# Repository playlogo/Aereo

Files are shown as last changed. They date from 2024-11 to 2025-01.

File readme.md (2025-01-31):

# Aereo - CO2 & PM2.5 Air Sensor with custom PCB

A DIY IoT air-quality sensor using a `Senseair S8` for CO2 and a `PMS5003` for particulate matter.

Features:

- ESP32c3 firmware to publish measurements to influxDB
- Custom PCB for easy assembly
- Grafana dashboard to display data

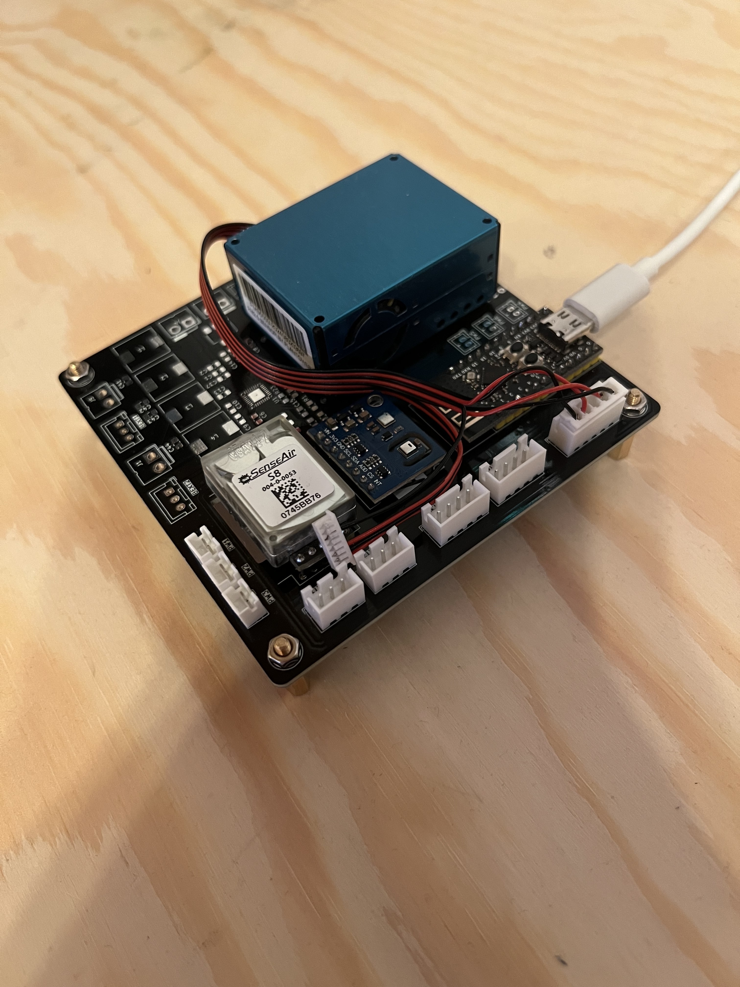
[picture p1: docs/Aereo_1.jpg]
Picture of assembeld Aereo PCB
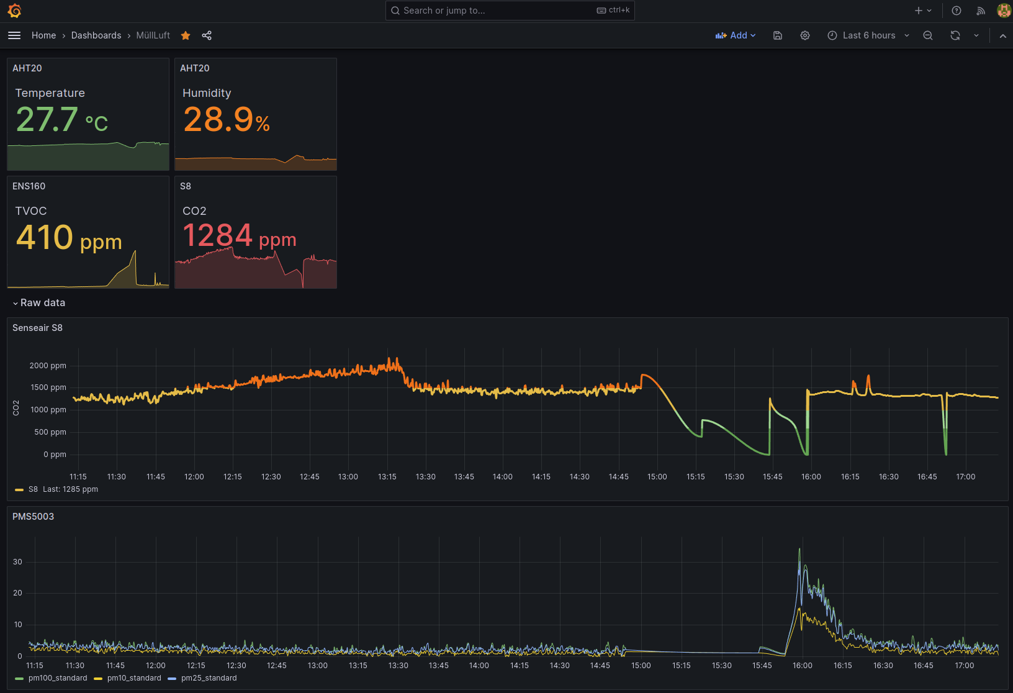
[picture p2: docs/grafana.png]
Screenshot of the grafana dashboard
|||
|-|-|
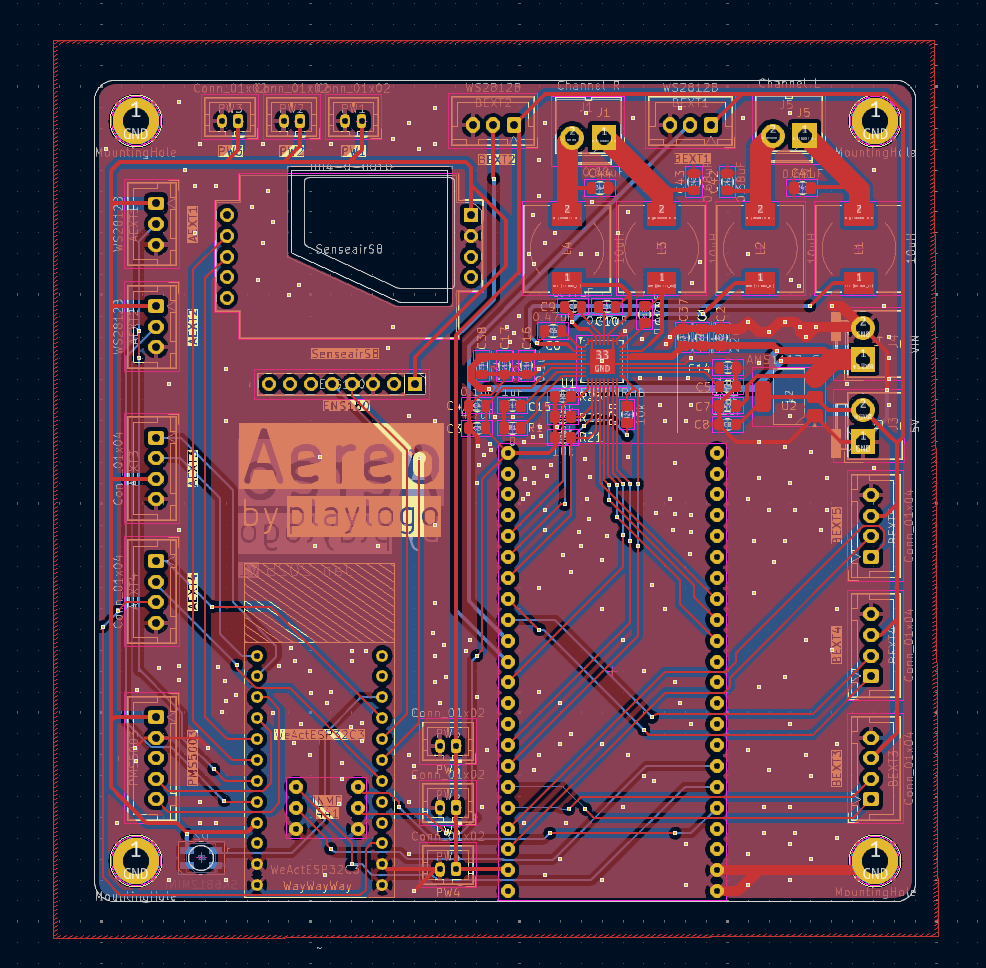
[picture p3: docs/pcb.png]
Picture of PCB design in KiCAD
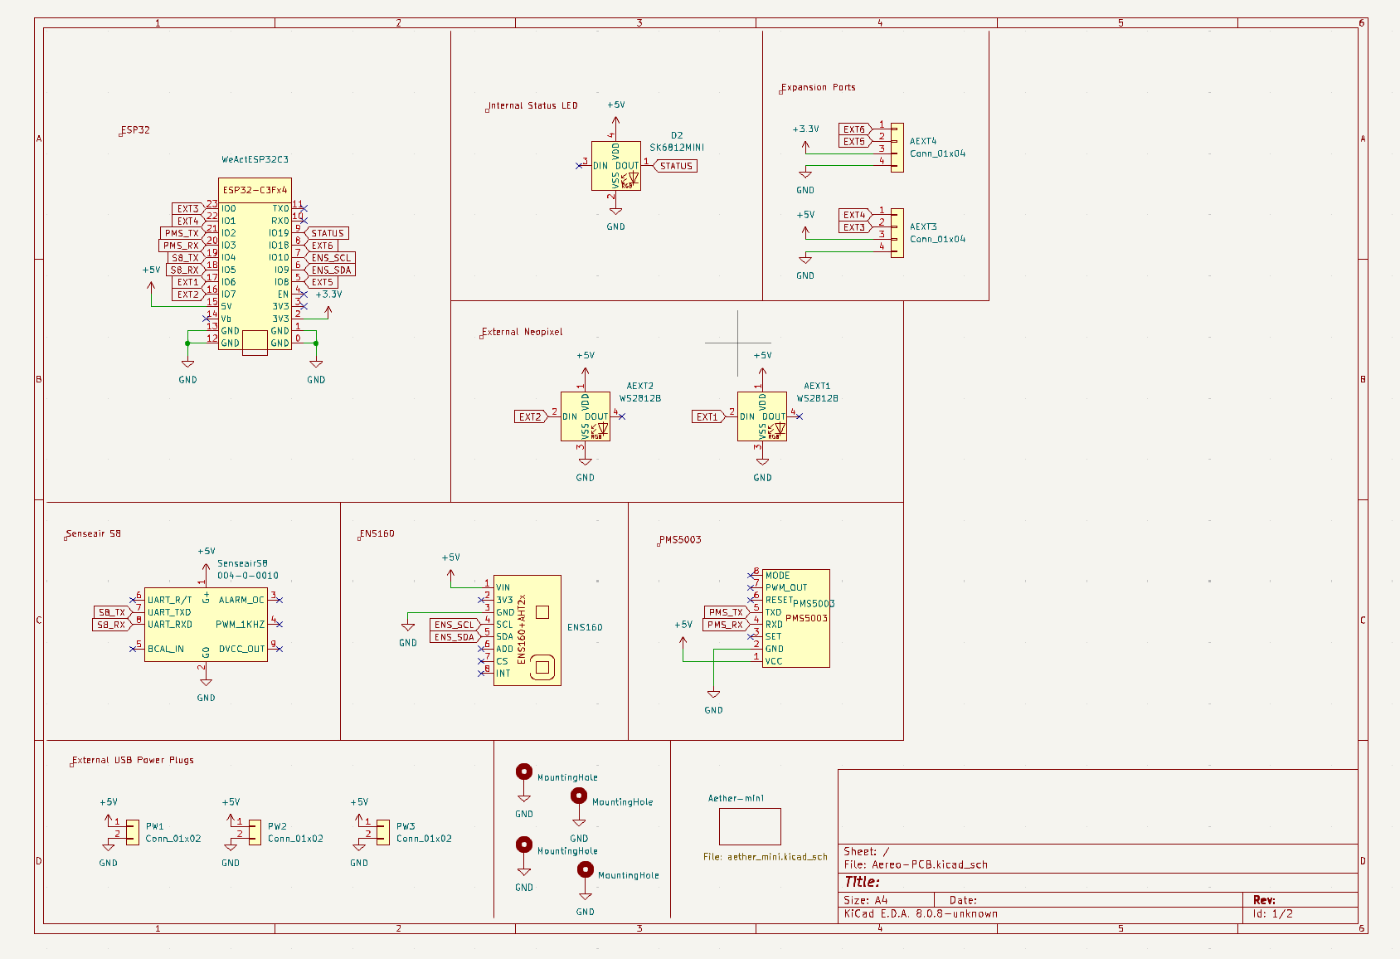
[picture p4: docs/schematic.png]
|||

## Tutorial

### Installing InfluxDB & Grafana using docker

1. Clone this repo: `git clone https://github.com/playlogo/Aereo.git`
2. Run `docker compose up -d`

3. Setup Grafana at: `http://<ip>:3000`
4. Setup InfluxDB at: `http://<ip>:8086`

5. Follow [this guide](https://www.influxdata.com/blog/getting-started-influxdb-grafana/) to add InfluxDB as a Datasource to Grafana
6. Import the Grafana dashboard:
    - Create a new empty dashboard: `Home` -> `Dashboards` -> `New`
    - Click the little gear icon to get to the `Dashboard Settings`
    - Go to the `JSON Model` tab
    - Copy the contents of the `grafana_dashboard.json` file and paste them into the editor
    - Hit `Save Changes` and reload - voilà (you might still need to change the Datasource of each Graph to the one you just created)

Optional: Create your own dashboard following the guide linked above (don't forget to hit save!)

### Flashing the ESP32c3

1. Open `.vscode/Aereo.code-workspace` using VSCode, make sure you have [PlatformIO](https://platformio.org/install/ide?install=vscode) installed and setup
2. Create `Aereo/src/secrets.h` with the following content:

```cpp
#define WIFI_SSID "NEIGHBORS_WIFI"
#define WIFI_PASSWORD "123456789"

#define INFLUXDB_URL "http://192.168.178.64:8086/"
#define INFLUXDB_TOKEN "token please" // Guide: https://docs.influxdata.com/influxdb3/cloud-serverless/admin/tokens/create-token/
#define INFLUXDB_ORG "bumble"
#define INFLUXDB_BUCKET "aereo" // Guide: https://docs.influxdata.com/influxdb/v2/admin/buckets/create-bucket/
```

3. Build & Upload to the ESP32c3: `CTRL+P` -> `PlatformIO: Upload`
4. The neopixel should blink blue while the ESP connects to wifi, when connected it should turn off - if it continues showing one static color, one of the sensors has not been detected -> Check serial output: `CTRL+P` -> `PlatformIO: Upload and Monitor`

## Hardware

Required components:

- `ENS160-AHT21`: Temp + TVOC sensor ~4€ on aliexpress
- `Senseair S8`: [NDIR](https://en.wikipedia.org/wiki/Nondispersive_infrared_sensor) CO2 Sensor ~20€ on aliexpress
- `PMS5003`:  Particulate matter sensor ~14€ on aliexpress
- `WeAct ESP32C3 CoreBoard`: ~4€ on aliexpress
- `SK6812 mini e`: 1x ARGB status LED ~3€ on aliexpress (for 100pcs)

PCB:

- Houses two independent projects to save costs, the right half can simply be ignored
- Exposed connectors:
  - 2x 3 Pin (5V, GND, Data)
  - 2x 4 Pin (5V, GND, Data, Data)
  - 3x Power (5V, GND)
- Size: 100x100mm

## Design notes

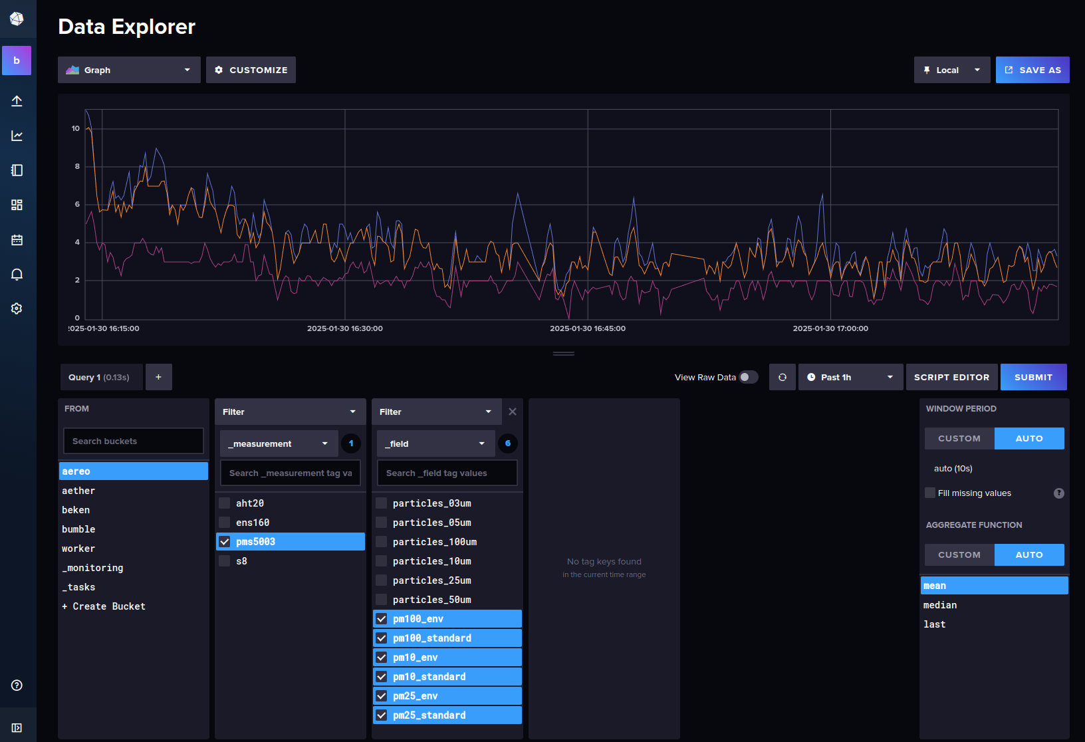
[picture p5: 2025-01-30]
docs/influxDB.png

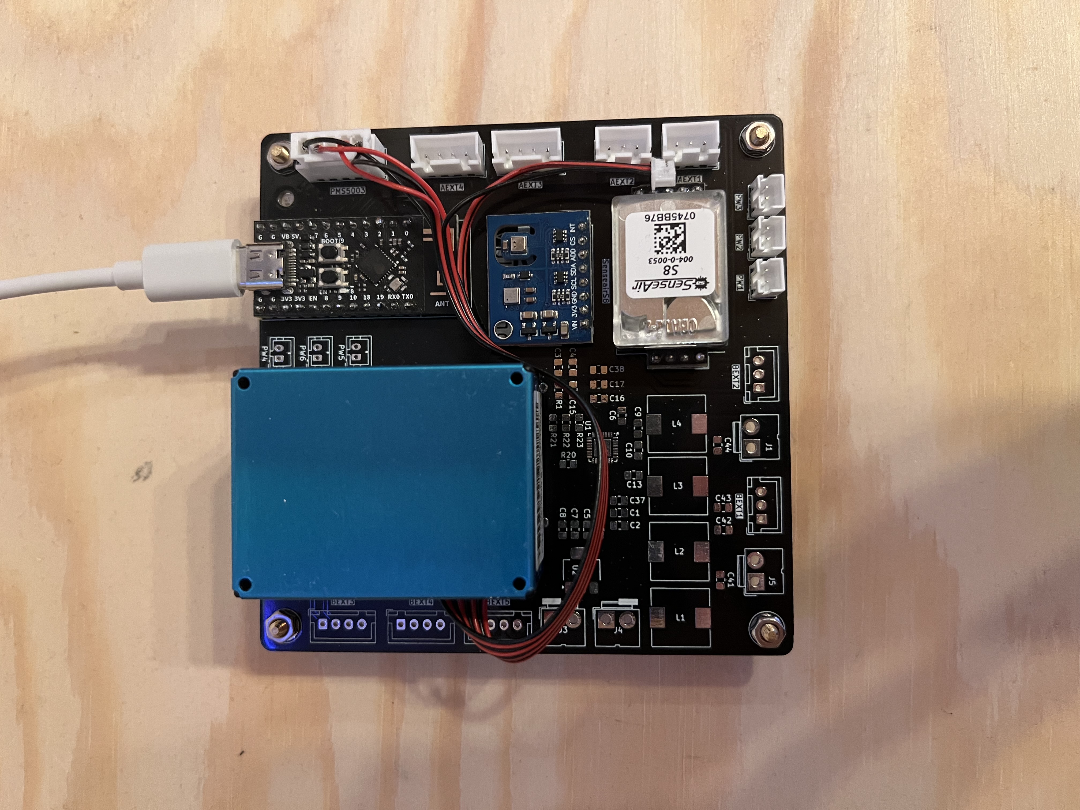
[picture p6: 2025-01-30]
docs/Aereo_2.jpg

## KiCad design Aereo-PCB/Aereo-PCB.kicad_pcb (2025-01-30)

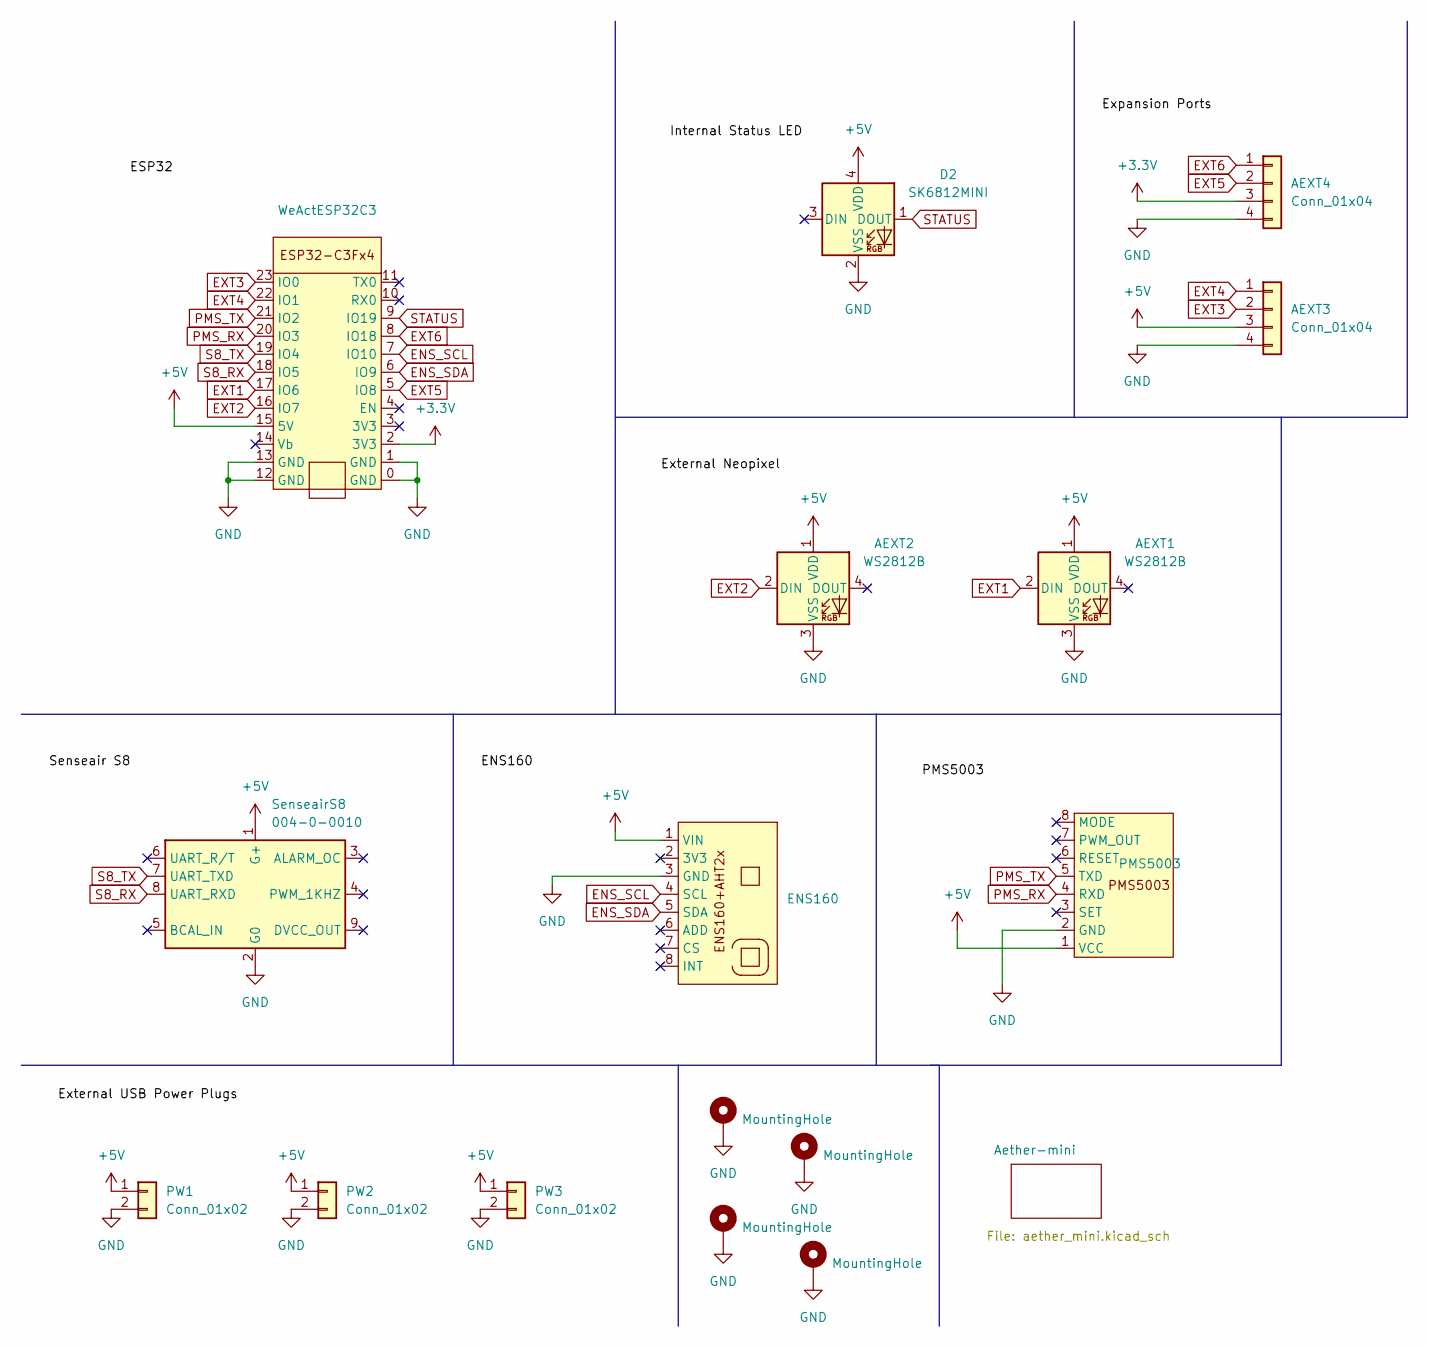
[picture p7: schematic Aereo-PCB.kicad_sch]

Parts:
AEXT1, AEXT2: WS2812B; JST_XH_B3B-XH-A_1x03_P2.50mm_Vertical
AEXT3, AEXT4: Conn_01x04; JST_XH_B4B-XH-A_1x04_P2.50mm_Vertical
D2: SK6812MINI; LED_SK6812MINI_PLCC4_3.5x3.5mm_P1.75mm
ENS160: PinHeader_1x08_P2.54mm_Vertical
H1, H2, H3, H4: MountingHole; MountingHole_3.2mm_M3_DIN965_Pad
PMS5003: JST_XH_B5B-XH-A_1x05_P2.50mm_Vertical
PW1, PW2, PW3: Conn_01x02; JST_PH_B2B-PH-K_1x02_P2.00mm_Vertical
SenseairS8: 004-0-0010; Senseair_S8_Down
WeActESP32C3: WeAct ESP32-C3Fx4 Core mini

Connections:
+3.3V: AEXT4.3, WeActESP32C3.2 (3V3)
+5V: AEXT1.1 (VDD), AEXT2.1 (VDD), AEXT3.3, D2.4 (VDD), ENS160.1 (VIN), PMS5003.1 (VCC), PW1.1, PW2.1, PW3.1, SenseairS8.1 (G+), WeActESP32C3.15 (5V)
ENS_SCL: ENS160.4 (SCL), WeActESP32C3.7 (IO10)
ENS_SDA: ENS160.5 (SDA), WeActESP32C3.6 (IO9)
EXT1: AEXT1.2 (DIN), WeActESP32C3.17 (IO6)
EXT2: AEXT2.2 (DIN), WeActESP32C3.16 (IO7)
EXT3: AEXT3.2, WeActESP32C3.23 (IO0)
EXT4: AEXT3.1, WeActESP32C3.22 (IO1)
EXT5: AEXT4.2, WeActESP32C3.5 (IO8)
EXT6: AEXT4.1, WeActESP32C3.8 (IO18)
GND: AEXT1.3 (VSS), AEXT2.3 (VSS), AEXT3.4, AEXT4.4, D2.2 (VSS), ENS160.3 (GND), H1.1, H2.1, H3.1, H4.1, PMS5003.2 (GND), PW1.2, PW2.2, PW3.2, SenseairS8.2 (G0), WeActESP32C3.0 (GND), WeActESP32C3.1 (GND), WeActESP32C3.12 (GND), WeActESP32C3.13 (GND); also elsewhere on the board
PMS_RX: PMS5003.4 (RXD), WeActESP32C3.20 (IO3)
PMS_TX: PMS5003.5 (TXD), WeActESP32C3.21 (IO2)
S8_RX: SenseairS8.8 (UART_RXD), WeActESP32C3.18 (IO5)
S8_TX: SenseairS8.7 (UART_TXD), WeActESP32C3.19 (IO4)
STATUS: D2.1 (DOUT), WeActESP32C3.9 (IO19)

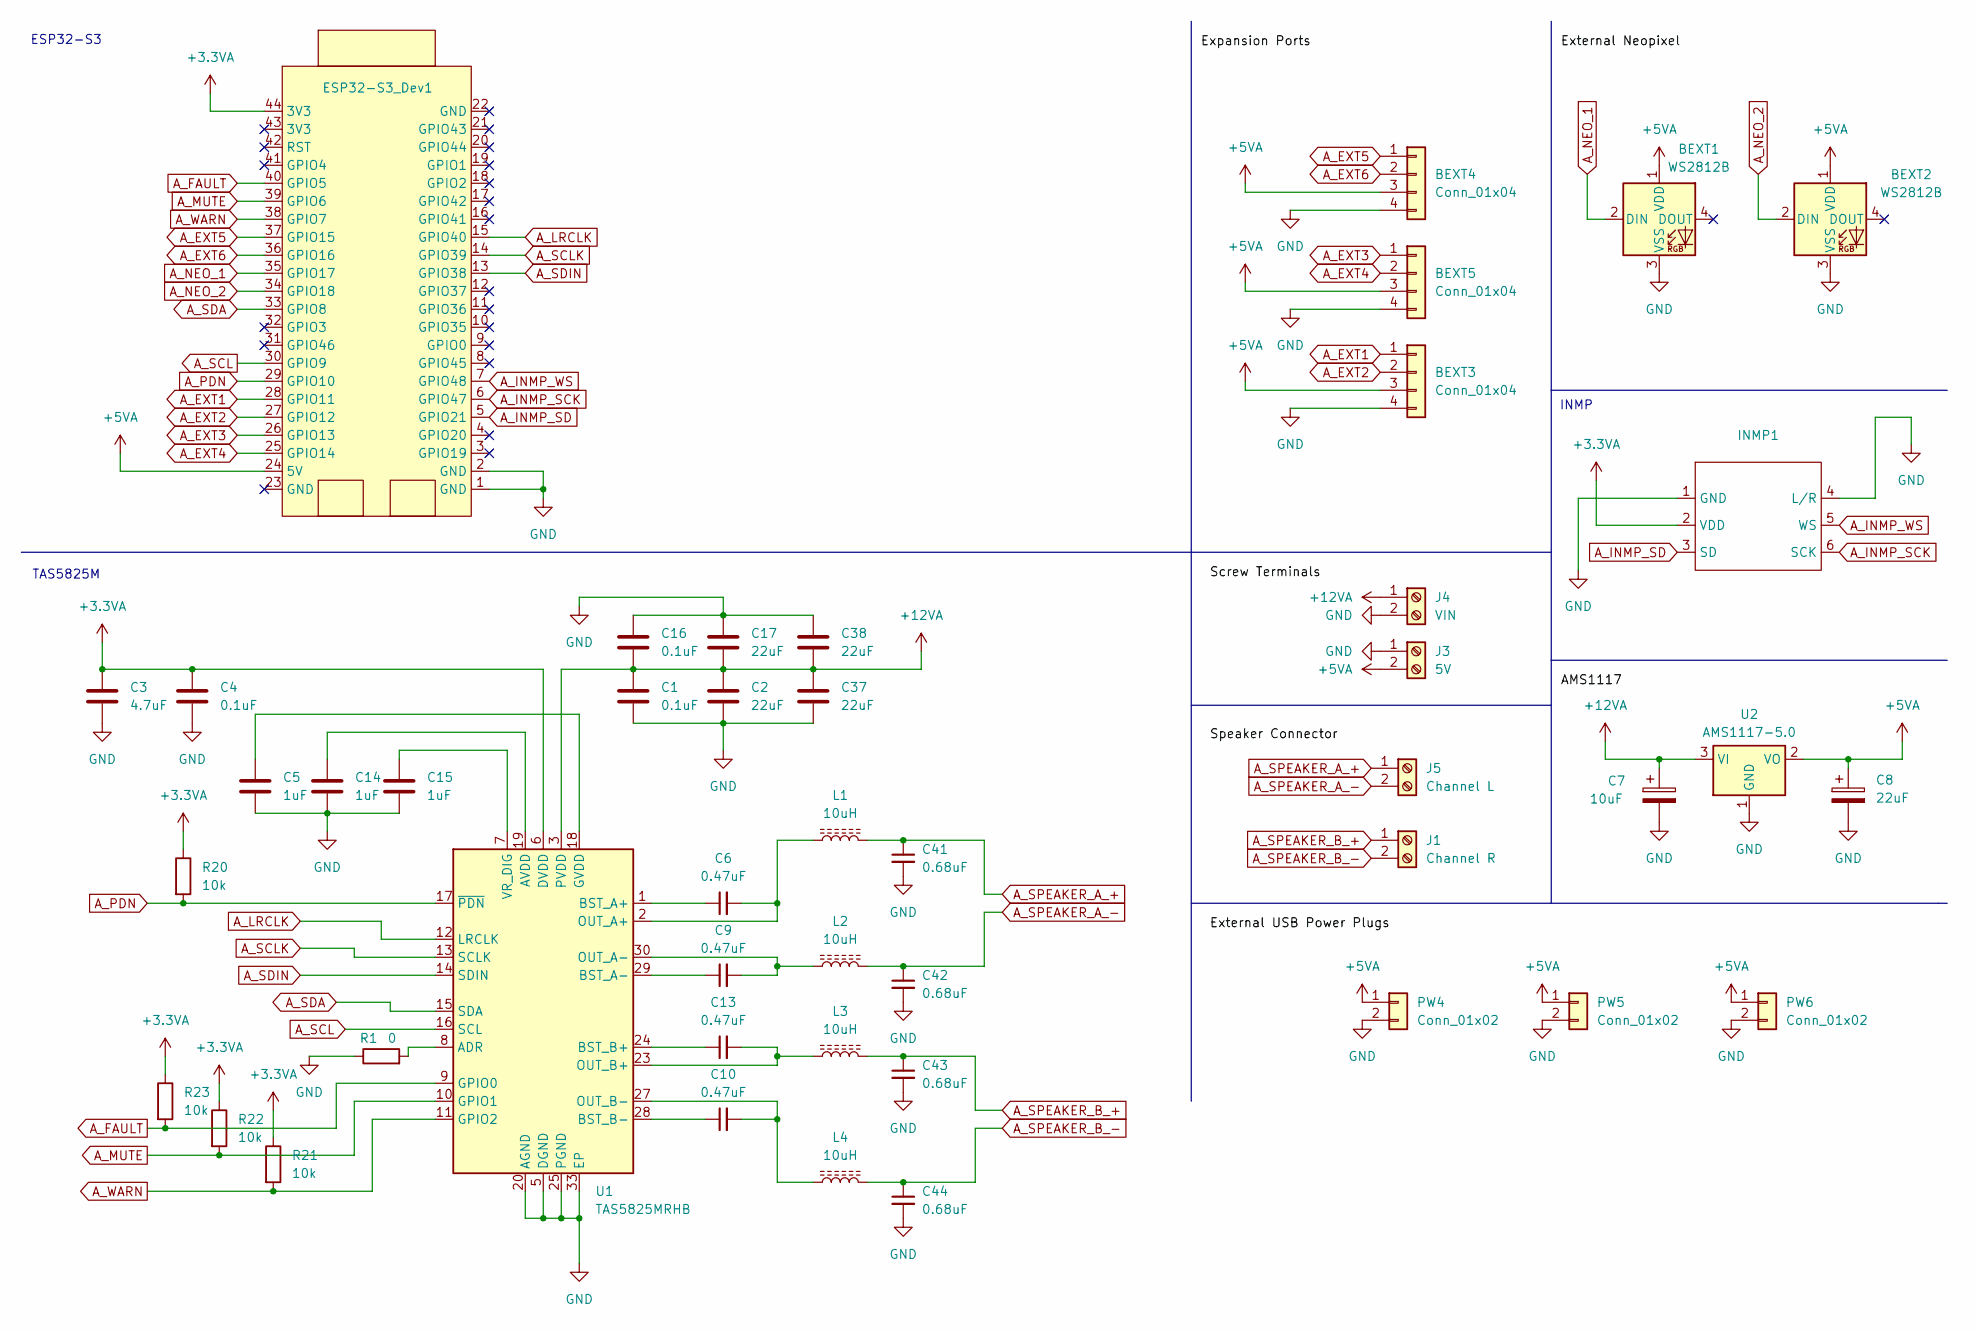
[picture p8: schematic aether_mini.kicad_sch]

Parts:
BEXT1, BEXT2: WS2812B; JST_XH_B3B-XH-A_1x03_P2.50mm_Vertical
BEXT3, BEXT4, BEXT5: Conn_01x04; JST_XH_B4B-XH-A_1x04_P2.50mm_Vertical
C1, C4, C16: 0.1uF; C_0805_2012Metric_Pad1.18x1.45mm_HandSolder
C2, C8, C17, C37, C38: 22uF; C_0805_2012Metric_Pad1.18x1.45mm_HandSolder
C3: 4.7uF; C_0805_2012Metric_Pad1.18x1.45mm_HandSolder
C5, C14, C15: 1uF; C_0805_2012Metric_Pad1.18x1.45mm_HandSolder
C6, C9, C10, C13: 0.47uF; C_0805_2012Metric_Pad1.18x1.45mm_HandSolder
C7: 10uF; C_0805_2012Metric_Pad1.18x1.45mm_HandSolder
C41, C42, C43, C44: 0.68uF; C_0805_2012Metric_Pad1.18x1.45mm_HandSolder
ESP32-S3_Dev1: ESP32-S3-Dev
INMP1: INMP441
J1: Channel R; JWT_A3963_1x02_P3.96mm_Vertical
J3: 5V; JWT_A3963_1x02_P3.96mm_Vertical
J4: VIN; JWT_A3963_1x02_P3.96mm_Vertical
J5: Channel L; JWT_A3963_1x02_P3.96mm_Vertical
L1, L2, L3, L4: 10uH; L_10.4x10.4_H4.8
PW4, PW5, PW6: Conn_01x02; JST_PH_B2B-PH-K_1x02_P2.00mm_Vertical
R1: 0; R_0805_2012Metric_Pad1.20x1.40mm_HandSolder
R20, R21, R22, R23: 10k; R_0805_2012Metric_Pad1.20x1.40mm_HandSolder
U1: TAS5825MRHB; VQFN-32-1EP_5x5mm_P0.5mm_EP3.1x3.1mm
U2: AMS1117-5.0; SOT-223-3_TabPin2

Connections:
+3.3VA: C3.1, C4.1, ESP32-S3_Dev1.44 (3V3), INMP1.2 (VDD), R20.1, R21.1, R22.1, R23.1, U1.6 (DVDD)
+5VA: BEXT1.1 (VDD), BEXT2.1 (VDD), BEXT3.3, BEXT4.3, BEXT5.3, C8.1, ESP32-S3_Dev1.24 (5V), J3.2, PW4.1, PW5.1, PW6.1, U2.2 (VO)
+12VA: C1.1, C2.1, C7.1, C16.2, C17.2, C37.1, C38.2, J4.1, U1.3 (PVDD), U1.4 (PVDD), U1.21 (PVDD), U1.22 (PVDD), U2.3 (VI)
A_EXT1: BEXT3.1, ESP32-S3_Dev1.28 (GPIO11)
A_EXT2: BEXT3.2, ESP32-S3_Dev1.27 (GPIO12)
A_EXT3: BEXT5.1, ESP32-S3_Dev1.26 (GPIO13)
A_EXT4: BEXT5.2, ESP32-S3_Dev1.25 (GPIO14)
A_EXT5: BEXT4.1, ESP32-S3_Dev1.37 (GPIO15)
A_EXT6: BEXT4.2, ESP32-S3_Dev1.36 (GPIO16)
A_FAULT: ESP32-S3_Dev1.40 (GPIO5), R23.2, U1.9 (GPIO0)
A_INMP_SCK: ESP32-S3_Dev1.6 (GPIO47), INMP1.6 (SCK)
A_INMP_SD: ESP32-S3_Dev1.5 (GPIO21), INMP1.3 (SD)
A_INMP_WS: ESP32-S3_Dev1.7 (GPIO48), INMP1.5 (WS)
A_LRCLK: ESP32-S3_Dev1.15 (GPIO40), U1.12 (LRCLK)
A_MUTE: ESP32-S3_Dev1.39 (GPIO6), R22.2, U1.10 (GPIO1)
A_NEO_1: BEXT1.2 (DIN), ESP32-S3_Dev1.35 (GPIO17)
A_NEO_2: BEXT2.2 (DIN), ESP32-S3_Dev1.34 (GPIO18)
A_PDN: ESP32-S3_Dev1.29 (GPIO10), R20.2, U1.17 (~PDN)
A_SCL: ESP32-S3_Dev1.30 (GPIO9), U1.16 (SCL)
A_SCLK: ESP32-S3_Dev1.14 (GPIO39), U1.13 (SCLK)
A_SDA: ESP32-S3_Dev1.33 (GPIO8), U1.15 (SDA)
A_SDIN: ESP32-S3_Dev1.13 (GPIO38), U1.14 (SDIN)
A_SPEAKER_A_+: C41.1, J5.1, L1.2
A_SPEAKER_A_-: C42.1, J5.2, L2.2
A_SPEAKER_B_+: C43.1, J1.1, L3.2
A_SPEAKER_B_-: C44.1, J1.2, L4.2
A_WARN: ESP32-S3_Dev1.38 (GPIO7), R21.2, U1.11 (GPIO2)
GND: BEXT1.3 (VSS), BEXT2.3 (VSS), BEXT3.4, BEXT4.4, BEXT5.4, C1.2, C2.2, C3.2, C4.2, C5.2, C7.2, C8.2, C14.2, C15.2, C16.1, C17.1, C37.2, C38.1, C41.2, C42.2, C43.2, C44.2, ESP32-S3_Dev1.1 (GND), ESP32-S3_Dev1.2 (GND), INMP1.1 (GND), INMP1.4 (L/R), J3.1, J4.2, PW4.2, PW5.2, PW6.2, R1.1, U1.5 (DGND), U1.20 (AGND), U1.25 (PGND), U1.26 (PGND), U1.31 (PGND), U1.32 (PGND), U1.33 (EP), U2.1 (GND); also elsewhere on the board
unnamed: R1.2, U1.8 (ADR)
unnamed: C14.1, U1.19 (AVDD)
unnamed: C6.1, U1.1 (BST_A+)
unnamed: C9.1, U1.29 (BST_A-)
unnamed: C13.1, U1.24 (BST_B+)
unnamed: C10.1, U1.28 (BST_B-)
unnamed: C5.1, U1.18 (GVDD)
unnamed: C6.2, L1.1, U1.2 (OUT_A+)
unnamed: C9.2, L2.1, U1.30 (OUT_A-)
unnamed: C13.2, L3.1, U1.23 (OUT_B+)
unnamed: C10.2, L4.1, U1.27 (OUT_B-)
unnamed: C15.1, U1.7 (VR_DIG)

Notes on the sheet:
ESP32-S3
INMP
TAS5825M

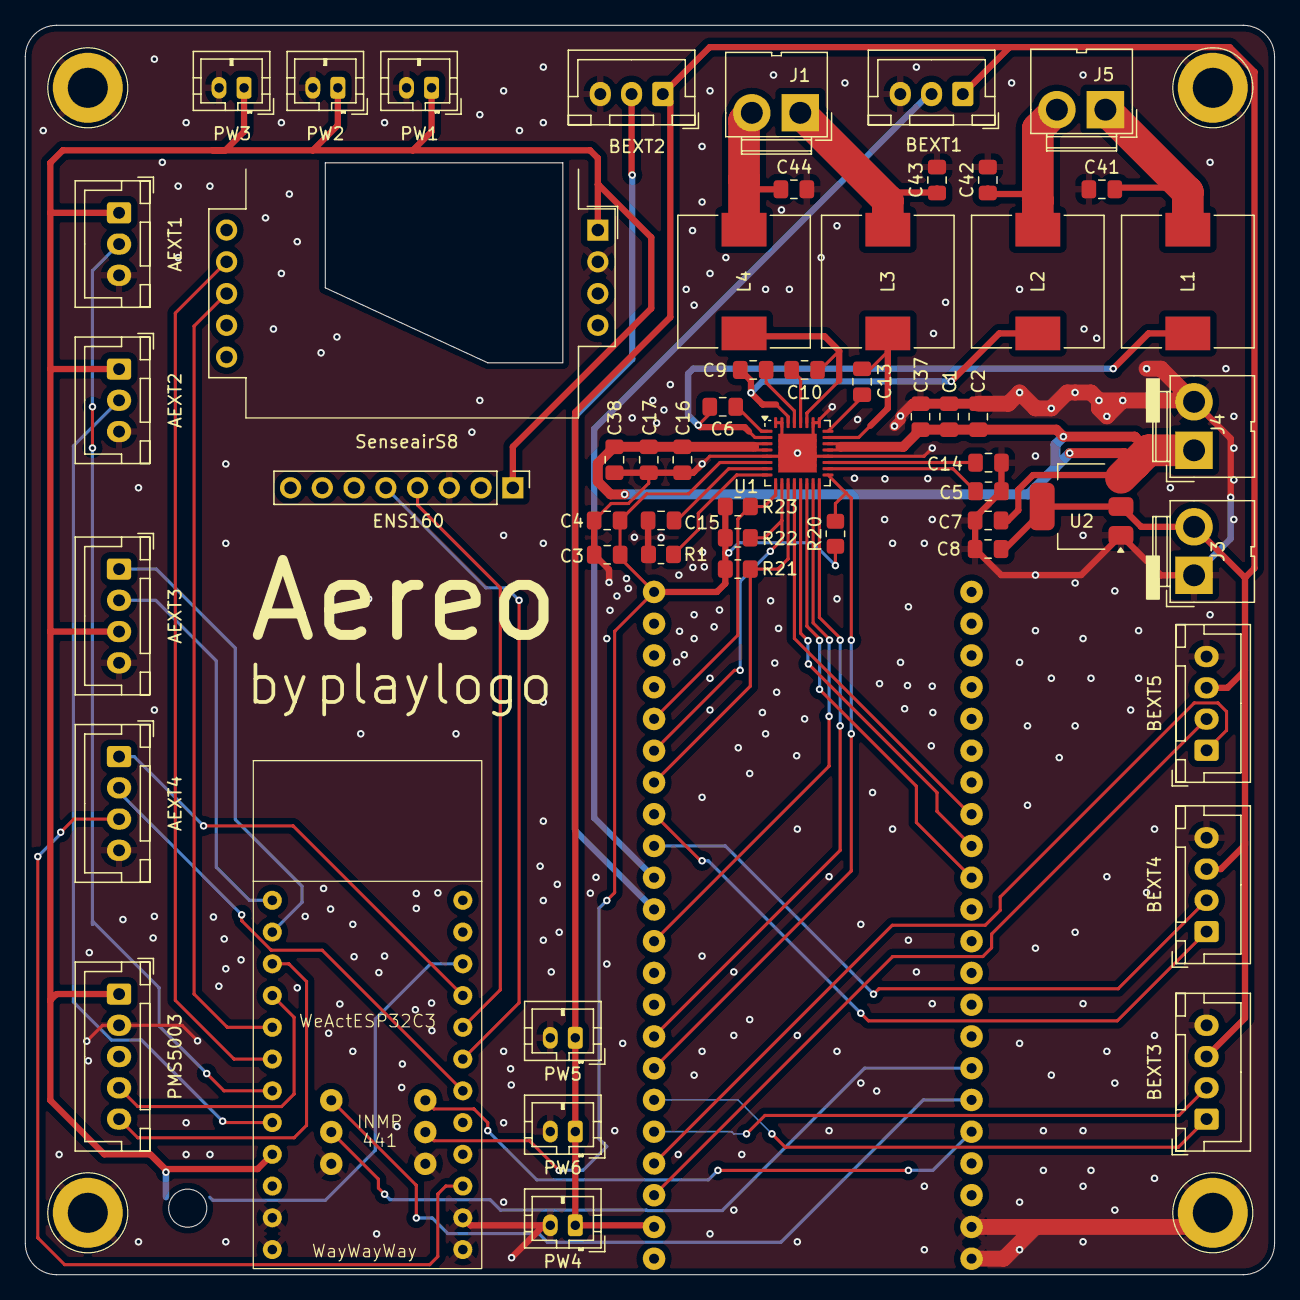
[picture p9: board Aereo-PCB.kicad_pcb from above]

Board: 2 copper layers, 99.9 x 99.9 mm, 62 parts (1 on the bottom side), 55 nets.

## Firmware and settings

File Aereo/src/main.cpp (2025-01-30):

#include <Arduino.h>

// Sensors
#include "sensors/pms5003.h"
#include "sensors/aht20.h"
#include "sensors/s8.h"

// Utils
#include "utils/influxdb.h"

// Neopixel
#include "utils/neopixel.h"

// Setup
void setup()
{
    Serial.begin(115200);

    neopixelSetup();

    wifiConnect();
    influxDBSetup();

    // Sensors
    bool enable_PMS5003 = setupPMS5003();
    bool enable_AHT20AndENS160 = setupAHT20AndENS160();
    bool enable_S8 = setupS8();

    // FreeRTOS
    if (enable_PMS5003)
    {
        xTaskCreate(loopPMS5003, "loopPMS5003", 10000, NULL, 1, NULL);
    }

    if (enable_AHT20AndENS160)
    {
        xTaskCreate(loopAHT20, "loopAHT20", 10000, NULL, 1, NULL);
        xTaskCreate(loopENS160, "loopENS160", 10000, NULL, 1, NULL);
    }

    if (enable_S8)
    {
        xTaskCreate(loopS8, "loopS8", 10000, NULL, 1, NULL);
    }

    setColor(enable_PMS5003 ? 0 : 40, enable_AHT20AndENS160 ? 0 : 40, enable_S8 ? 0 : 40);
}

void loop()
{
    delay(1000);
}

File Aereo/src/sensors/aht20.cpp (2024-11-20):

#include "aht20.h"

#include "../utils/common.h"
#include "../utils/influxdb.h"

#include <Wire.h>
#include <Adafruit_AHTX0.h>
#include <ScioSense_ENS160.h>

ScioSense_ENS160 ens160(ENS160_I2CADDR_1);
Adafruit_AHTX0 aht;

int tempC;
int humidity;

Point Sensor_AHT20("aht20");
Point Sensor_ENS160("ens160");

bool setupAHT20AndENS160()
{
    // AHT20Swtich
    Wire.setPins(9, 10); // Switch I2C pins

    if (!aht.begin())
    {
        Serial.println("AHT20 sensor not found!");
        return false;
    }
    else
    {
        Serial.println("AHT20 sensor found!");
    }

    // ENS160
    ens160.begin();

    if (ens160.available())
    {
        Sensor_ENS160.addTag("major_rev", String(ens160.getMajorRev()));
        Sensor_ENS160.addTag("minor_rev", String(ens160.getMinorRev()));
        Sensor_ENS160.addTag("build", String(ens160.getBuild()));

        // Set standard mode
        ens160.setMode(ENS160_OPMODE_STD);

        Serial.print("ENS160 Sensor initialized");
    }
    else
    {
        Serial.println("ENS160 sensor not found!");
        return false;
    }

    return true;
}

void loopAHT20(void *parameter)
{
    while (1)
    {
        if (xSemaphoreTake(access_mutex, portMAX_DELAY) == pdTRUE)
        {
            sensors_event_t humidity1, temp;
            aht.getEvent(&humidity1, &temp);

            float org_temp = temp.temperature;
            float org_humidity = humidity1.relative_humidity;

            tempC = (org_temp);
            humidity = (org_humidity);

            Sensor_AHT20.clearFields();
            Sensor_AHT20.addField("temperature", org_temp);
            Sensor_AHT20.addField("humidity", org_humidity);

            // If no Wifi signal, try to reconnect it
            if (wifiMulti.run() != WL_CONNECTED)
            {
                Serial.println("Wifi connection lost");
            }

            if (!client.writePoint(Sensor_AHT20))
            {
                Serial.print("InfluxDB write failed: ");
                Serial.println(client.getLastErrorMessage());
            }
            else
            {
                Serial.println("AHT20 Data sent to InfluxDB");
            }
            xSemaphoreGive(access_mutex);
        }

        delay(987);
    }
}

void loopENS160(void *parameter)
{
    while (1)
    {
        if (xSemaphoreTake(access_mutex, portMAX_DELAY) == pdTRUE)
        {
            if (ens160.available())
            {
                ens160.set_envdata(tempC, humidity);

                ens160.measure(true);
                ens160.measureRaw(true);

                Sensor_ENS160.clearFields();
                Sensor_ENS160.addField("aqi", ens160.getAQI());
                Sensor_ENS160.addField("tvoc", ens160.getTVOC());
                Sensor_ENS160.addField("eco2", ens160.geteCO2());

                // If no Wifi signal, try to reconnect it
                if (wifiMulti.run() != WL_CONNECTED)
                {
                    Serial.println("Wifi connection lost");
                }

                client.writePoint(Sensor_ENS160);

                Serial.println("ENS160 Data sent to InfluxDB");
            }

            xSemaphoreGive(access_mutex);
        }

        delay(1122);
    }
}

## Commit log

2024-11-18 Initial prototype
2024-11-19 Added senseair s8 sensor!
2024-11-19 Changed tmp type to floats, add support for custom pins for I2C
2025-01-30 Added Custom PCB, added debug neopixel
    [Aereo-PCB.kicad_pcb, Aereo-PCB.kicad_sch, aether_mini.kicad_sch]
